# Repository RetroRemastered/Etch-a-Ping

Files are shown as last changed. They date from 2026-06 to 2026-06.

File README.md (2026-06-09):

# Etch-a-PING: Raspberry Pi Pico Pong

`PING` is a MicroPython Pong-inspired game for a Raspberry Pi Pico with real potentiometer paddles, an ILI9225 SPI LCD, a MAX98357A I2S amplifier, and a momentary start button.

It boots to a title screen, plays with an Etch A Sketch-style grey-and-black look, uses classic Pong-like sound effects, and keeps score to 11 with win-by-2 rules.

## Documentation

- [Build tutorial](TUTORIAL.md)
- [Bill of materials](BOM.md)
- [3D print files](3d-print)

## Features

- Raspberry Pi Pico / Pico W firmware in MicroPython
- ILI9225 LCD driver included
- Two analog potentiometer paddles
- MAX98357A I2S audio using RP2040 PIO
- Momentary start button
- 3D printed enclosure files included
- Final score screen
- First to 11, win by 2
- Battery-power notes for TP4056/LiPo builds

## Quick Wiring Summary

| Device | Pico pins |
| --- | --- |
| ILI9225 LCD | `GP17`, `GP18`, `GP19`, `GP20`, `GP21`, `GP22` |
| Potentiometers | `GP26`, `GP27`, `3V3 OUT`, `GND` |
| MAX98357A amp | `GP10`, `GP11`, `GP12` |
| Start button | `GP13`, `GND` |

See [BOM.md](BOM.md) and [TUTORIAL.md](TUTORIAL.md) for the complete wiring tables.

## Install

1. Flash current MicroPython for Raspberry Pi Pico onto the Pico.
2. Open `main.py` in Thonny.
3. Save it to the Pico as `main.py`.
4. Reset the Pico or unplug/replug it.

## 3D Printing

The enclosure files are in [`3d-print`](3d-print):

- [`etch-a-ping-front.stl`](3d-print/etch-a-ping-front.stl)
- [`etch-a-ping-back.stl`](3d-print/etch-a-ping-back.stl)
- [`etch-a-ping-knob.stl`](3d-print/etch-a-ping-knob.stl), print two

## Tuning

- If the screen is only white, the backlight is on but the display is not receiving commands. Recheck `CS`, `RST`, `RS`, `CLK`, and `SDI`.
- To make the game faster or slower, change the `time.sleep_ms(12)` line at the end of the game loop.

## Sources Checked

- Pico pinout: https://pico.pinout.xyz/
- MAX98357A pinout reference: https://learn.adafruit.com/adafruit-max98357-i2s-class-d-mono-amp/pinouts
- ILI9225 register sequence reference: https://os.mbed.com/users/Arman92/code/ILI9225_SPI_TFT/file/cc93245bb6d0/TFT_22_ILI9225.cpp

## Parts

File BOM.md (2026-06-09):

# Bill of Materials

This build is a handheld Raspberry Pi Pico Pong console with real paddle controls, an ILI9225 color LCD, I2S audio, and a start button.

## Required Parts

| Qty | Part | Notes |
| --- | --- | --- |
| 1 | Raspberry Pi Pico | No need for Pico 2. |
| 1 | ILI9225 SPI LCD module | 176 x 220 display, red breakout board. |
| 2 | 10k potentiometers | Linear taper preferred for paddle controls. |
| 1 | MAX98357A I2S mono amplifier | Drives the speaker from Pico digital audio. |
| 1 | Game Boy DMG speaker | 8 ohm speaker for the amp output. |
| 1 | Momentary pushbutton | Start button. |
| 1 | 3.7V LiPo battery | Small Battery that actually fits. |
| 1 | TP4056 LiPo charger/protection board | USB-C version. |
| 1 | Locking on/off switch | Put this between TP4056 `OUT+` and Pico `VSYS`. |
| Several | Jumper wires or hookup wire | 30 AWG is what I use. |

## Case Hardware

| Qty | Part | Notes |
| --- | --- | --- |
| 4 | `M2x4mm` machine screws | Used to mount the screen. |
| 4 | `M2x4x3.2` heat-set inserts | Used in the printed case so the back can screw on cleanly. |
| 4 | `M2x8mm` machine screws | Used with the heat-set inserts to close the two case halves. |

## Part Links

Add direct purchase links here for the exact parts used in your build.

| Part | Link |
| --- | --- |
| Raspberry Pi Pico or Pico W | https://amzn.to/4ftIaCY |
| ILI9225 SPI LCD module | https://amzn.to/4e5MO7L |
| 10k potentiometers | https://amzn.to/4dSDFkc |
| MAX98357A I2S mono amplifier | https://amzn.to/4ogg4NH |
| Game Boy DMG speaker | https://amzn.to/3S9yOTa |
| Momentary pushbutton | https://amzn.to/4um4aTU |
| 3.7V LiPo battery | https://amzn.to/49N2Diw |
| TP4056 LiPo charger/protection board | https://amzn.to/3RUsTRW |
| Locking on/off switch | https://amzn.to/4xhQewU |
| Hookup wire / jumper wire | https://amzn.to/3S8yR1x |
| `M2x4mm` screen screws | https://s.click.aliexpress.com/e/_c4rYxvI9 |
| `M2x4x3.2` heat-set inserts | https://s.click.aliexpress.com/e/_c3U6pgQp |
| `M2x8mm` case screws | https://s.click.aliexpress.com/e/_c4rYxvI9 |

## Tools

| Tool | Use |
| --- | --- |
| Soldering iron | Solder headers and wires. |
| Multimeter | Check continuity and voltages. |
| Computer with Thonny | Flash MicroPython and copy `main.py`. |
| USB cable | Pico programming and testing. |
| Heat-set insert tip or soldering iron | Install threaded inserts into the printed case. |

## Pin Summary

### ILI9225 LCD

| LCD signal | Pico pin |
| --- | --- |
| VCC | `3V3 OUT` |
| GND | `GND` |
| LED | `GP22` |
| CLK | `GP18` |
| SDI | `GP19` |
| RS / DC | `GP20` |
| RST | `GP21` |
| CS | `GP17` |

### Potentiometers

| Control | Pot outer leg | Pot wiper | Pot other outer leg |
| --- | --- | --- | --- |
| Left paddle | `3V3 OUT` | `GP26 / ADC0` | `GND` |
| Right paddle | `3V3 OUT` | `GP27 / ADC1` | `GND` |

If a paddle moves backward, swap that potentiometer's two outer-leg wires.

### MAX98357A Amplifier

| MAX98357A signal | Pico pin |
| --- | --- |
| Vin | `3V3 OUT` or `VSYS` |
| GND | `GND` |
| LRC | `GP10` |
| BCLK | `GP11` |
| DIN | `GP12` |

Connect the speaker to the amplifier screw terminal output. Do not connect a speaker directly to a Pico GPIO pin.

### Start Button

| Button leg | Pico pin |
| --- | --- |
| One side | `GP13` |
| Other side | `GND` |

The firmware uses the Pico internal pull-up resistor.

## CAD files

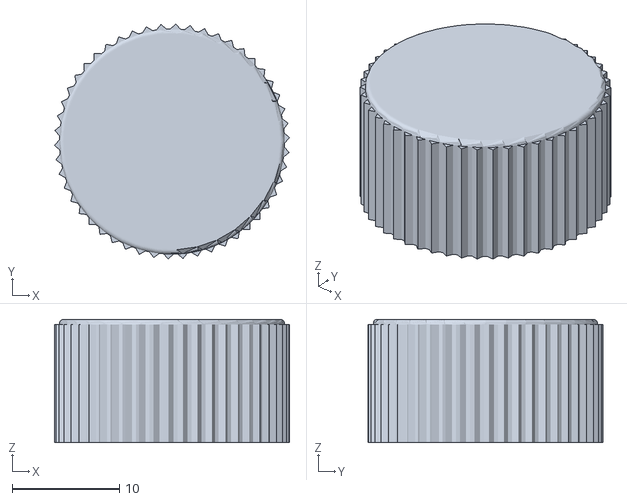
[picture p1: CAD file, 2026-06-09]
3d-print/etch-a-ping-knob.stl
21.9 x 21.9 x 11.5

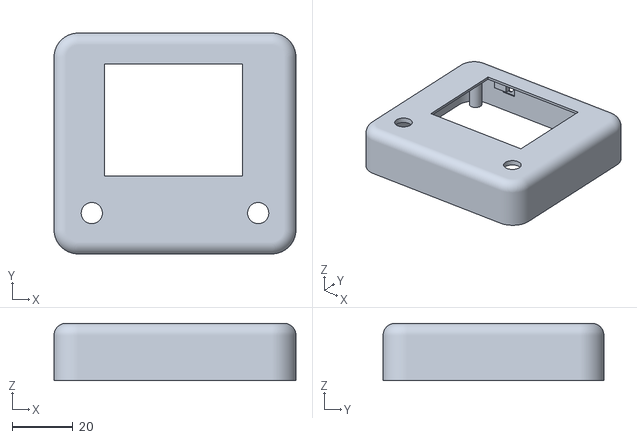
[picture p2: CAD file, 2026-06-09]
3d-print/etch-a-ping-front.stl
80.0 x 73.0 x 19.0

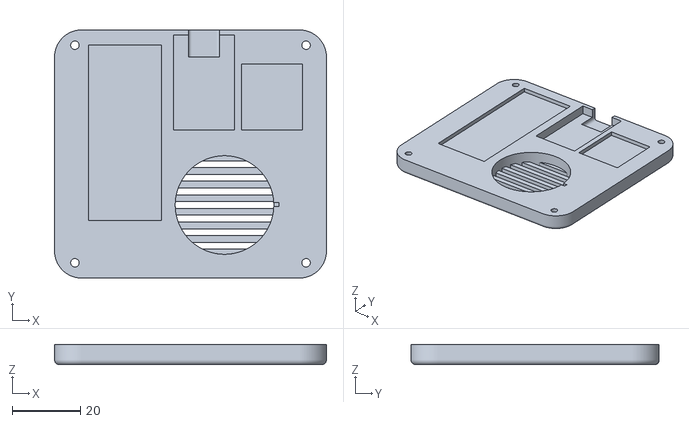
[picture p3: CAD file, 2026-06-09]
3d-print/etch-a-ping-back.stl
80.0 x 73.0 x 6.00

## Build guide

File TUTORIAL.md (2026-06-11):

# Build Tutorial

This written guide follows the same general flow as the video walkthrough: gather the parts, print the enclosure, wire the electronics in small sections, load the firmware, then close it up and play.

You can follow along with me as I build it in this video here: https://youtu.be/AFBS6jwd1_I

`PING` is a Pong-inspired game for Raspberry Pi Pico with real potentiometer paddles, an ILI9225 LCD, MAX98357A audio, a start button, and LiPo battery power.

## 1. Print the Enclosure

The printable parts are in the [`3d-print`](3d-print) folder:

| File | Use |
| --- | --- |
| [`etch-a-ping-front.stl`](3d-print/etch-a-ping-front.stl) | Front shell with the screen and controls. |
| [`etch-a-ping-back.stl`](3d-print/etch-a-ping-back.stl) | Back shell. |
| [`etch-a-ping-knob.stl`](3d-print/etch-a-ping-knob.stl) | Potentiometer knob. Print two knobs. |

Print one front, one back, and two knobs. Test-fit the screen, pots, start button, switch, speaker, Pico, battery, charger board, four `M2x4x3.2` heat-set inserts, four `M2x4mm` screen screws, and four `M2x8mm` case screws before soldering the final wiring. The case is tight, so it is easier to fix fit issues before the wires are attached.

Install the four `M2x4x3.2` heat-set inserts before final assembly. Use a heat-set insert tip or a soldering iron set to a moderate temperature, press each insert in slowly, and let the plastic cool before test-fitting the `M2x8mm` screws. The inserts should sit flush and straight so the back shell closes without stress.

## 2. Flash MicroPython

1. Download the latest MicroPython UF2 for your board:
   - Raspberry Pi Pico: https://micropython.org/download/RPI_PICO/
   - Raspberry Pi Pico W: https://micropython.org/download/RPI_PICO_W/
2. Hold the Pico `BOOTSEL` button while plugging it into USB.
3. Copy the downloaded `.uf2` file to the `RPI-RP2` drive.
4. The Pico will reboot into MicroPython.

After MicroPython is installed, open Thonny and make sure you can connect to the Pico.

## 3. Install the Game

1. Open [`main.py`](main.py) in Thonny.
2. Choose `File` -> `Save As...`.
3. Select `Raspberry Pi Pico`.
4. Save the file as exactly `main.py`.
5. Unplug and reconnect the Pico, or restart the backend in Thonny.

On boot, the screen shows `PING`. Press the start button to begin once the build is wired.

## 4. Prep the Main Parts

Before wiring everything together, mount or test-fit these parts in the printed front shell:

- ILI9225 display
- Two 10k potentiometers
- Momentary start button
- Locking power switch
- Speaker
- Heat-set inserts and case screws

Keep the Pico, MAX98357A amp, TP4056 charger board, and battery loose until the wiring is mostly finished. This makes it easier to route wires without fighting the case.

## 5. Wire the Display

Wire the ILI9225 display first. The display is the trickiest part of the build, so take your time here.

| LCD signal | Pico pin |
| --- | --- |
| VCC | `3V3 OUT` |
| GND | `GND` |
| LED | `GP22` |
| CLK | `GP18` |
| SDI | `GP19` |
| RS / DC | `GP20` |
| RST | `GP21` |
| CS | `GP17` |

If the screen stays white after installing the game, the backlight is powered but the display controller is not receiving commands. Check continuity on `CS`, `CLK`, `SDI`, `RS`, and `RST`.

## 6. Wire the Paddles

Each potentiometer is wired as a voltage divider.

| Control | Pot outer leg | Pot wiper | Pot other outer leg |
| --- | --- | --- | --- |
| Left paddle | `3V3 OUT` | `GP26 / ADC0` | `GND` |
| Right paddle | `3V3 OUT` | `GP27 / ADC1` | `GND` |

Use `3V3 OUT`, not `3V3_EN`. The `3V3_EN` pin controls the Pico regulator and should not be used as the power rail for the potentiometers.

If a paddle moves backward later, swap that potentiometer's two outer-leg wires.

## 7. Wire the Audio

Wire the MAX98357A I2S amplifier.

| MAX98357A signal | Pico pin |
| --- | --- |
| Vin | `3V3 OUT` or `VSYS` |
| GND | `GND` |
| LRC | `GP10` |
| BCLK | `GP11` |
| DIN | `GP12` |

Connect the speaker to the amplifier output terminals. Do not connect the speaker directly to the Pico.

If the amp is silent, connect the amp `SD` pin to `Vin` to force the amp on.

## 8. Wire the Start Button

Wire the normally open momentary switch:

| Button leg | Pico pin |
| --- | --- |
| One side | `GP13` |
| Other side | `GND` |

No external resistor is required because the firmware uses the Pico internal pull-up.

## 9. Wire Battery Power

Use a protected TP4056 charger board with a single-cell 3.7V LiPo.

| Connection | Destination |
| --- | --- |
| LiPo red | TP4056 `B+` |
| LiPo black | TP4056 `B-` |
| TP4056 `OUT+` | Locking switch, then Pico `VSYS` |
| TP4056 `OUT-` | Pico `GND` |

Do not connect battery power to `3V3 OUT`. Use `VSYS`.

The locking switch goes on the positive output side, between TP4056 `OUT+` and Pico `VSYS`. Charge the battery through the TP4056 USB port, not through the Pico USB port.

For small LiPo cells, make sure the TP4056 charge current is appropriate for the battery capacity.

## 10. Final Assembly

Once the screen, controls, audio, and battery wiring all work:

1. Place the screen into the front shell.
2. Secure the screen with four `M2x4mm` screws.
3. Install the potentiometers and knobs.
4. Install the start button and locking power switch.
5. Position the speaker so it is not pressing hard into the screen or Pico.
6. Secure the Pico, amplifier, TP4056 board, and battery.
7. Route wires so the back shell does not pinch them.
8. Close the case with four `M2x8mm` screws threaded into the heat-set inserts.

Power it on with the locking switch, wait for the `PING` title, then press the start button.

## 11. Gameplay

- The first player to reach 11 wins, but they must win by 2 points.
- The score is hidden during active play.
- After each point, the score appears briefly while the paddles can still move.
- After a match ends, the final score remains on screen until the start button is pressed.

## Troubleshooting

### Screen is white

The backlight is powered, but the display controller is not receiving commands. Check `VCC`, `GND`, `CS`, `CLK`, `SDI`, `RS`, and `RST`.

### Audio is silent

Check `Vin`, `GND`, `LRC`, `BCLK`, `DIN`, speaker wiring, and the amp `SD` pin.

### Paddles move backward

Swap the two outer legs of that potentiometer.

### Paddles feel too sensitive

Lower `PADDLE_SENSITIVITY` in `main.py`.

### Ball speed needs tuning

Change `BALL_SPEED` and `SERVE_SPEED` in `main.py`.

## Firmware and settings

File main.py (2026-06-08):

from machine import ADC, Pin, SPI
from rp2 import PIO, StateMachine, asm_pio
import random
import time


# ILI9225 red breakout screen pins, matching your soldered wiring.
LCD_LED = 22
LCD_SCK = 18   # Screen CLK
LCD_MOSI = 19  # Screen SDI
LCD_RS = 20
LCD_RST = 21
LCD_CS = 17

# Two potentiometers. Outer legs go to 3V3 and GND; center wipers go here.
POT_LEFT = 26   # ADC0
POT_RIGHT = 27  # ADC1

# MAX98357A I2S amp pins. These are digital pins so the ADC pins stay free.
I2S_LRC = 10
I2S_BCLK = 11
I2S_DIN = 12
START_BUTTON = 13
AUDIO_RATE = 16_000
AUDIO_VOLUME = 2250
PADDLE_SENSITIVITY = 4

PHYS_WIDTH = 176
PHYS_HEIGHT = 220
WIDTH = 220
HEIGHT = 176
PLAY_LEFT = 0
PLAY_RIGHT = WIDTH

BLACK = 0x0000
WHITE = 0xFFFF
BACKGROUND = 0x8410
FOREGROUND = BLACK
BALL_SPEED = 4
SERVE_SPEED = 3

DIGITS = {
    "0": ("111", "101", "101", "101", "111"),
    "1": ("010", "110", "010", "010", "111"),
    "2": ("111", "001", "111", "100", "111"),
    "3": ("111", "001", "111", "001", "111"),
    "4": ("101", "101", "111", "001", "001"),
    "5": ("111", "100", "111", "001", "111"),
    "6": ("111", "100", "111", "101", "111"),
    "7": ("111", "001", "010", "010", "010"),
    "8": ("111", "101", "111", "101", "111"),
    "9": ("111", "101", "111", "001", "111"),
}

LETTERS = {
    "G": ("01110", "10000", "10000", "10111", "10001", "10001", "01110"),
    "I": ("11111", "00100", "00100", "00100", "00100", "00100", "11111"),
    "N": ("10001", "11001", "10101", "10011", "10001", "10001", "10001"),
    "P": ("11110", "10001", "10001", "11110", "10000", "10000", "10000"),
}


class ILI9225:
    def __init__(self):
        self.spi = SPI(
            0,
            baudrate=16_000_000,
            polarity=0,
            phase=0,
            sck=Pin(LCD_SCK),
            mosi=Pin(LCD_MOSI),
        )
        self.led = Pin(LCD_LED, Pin.OUT, value=1)
        self.rs = Pin(LCD_RS, Pin.OUT, value=0)
        self.cs = Pin(LCD_CS, Pin.OUT, value=1)
        self.rst = Pin(LCD_RST, Pin.OUT, value=1)
        self.init()

    def write_command(self, value):
        self.rs(0)
        self.cs(0)
        self.spi.write(bytes([(value >> 8) & 0xFF, value & 0xFF]))
        self.cs(1)

    def write_data(self, value):
        self.rs(1)
        self.cs(0)
        self.spi.write(bytes([(value >> 8) & 0xFF, value & 0xFF]))
        self.cs(1)

    def write_register(self, reg, value):
        self.write_command(reg)
        self.write_data(value)

    def reset(self):
        self.rst(1)
        time.sleep_ms(5)
        self.rst(0)
        time.sleep_ms(20)
        self.rst(1)
        time.sleep_ms(80)

    def init(self):
        self.reset()

        self.write_register(0x10, 0x0000)
        self.write_register(0x11, 0x0000)
        self.write_register(0x12, 0x0000)
        self.write_register(0x13, 0x0000)
        self.write_register(0x14, 0x0000)
        time.sleep_ms(40)

        self.write_register(0x11, 0x0018)
        self.write_register(0x12, 0x6121)
        self.write_register(0x13, 0x006F)
        self.write_register(0x14, 0x495F)
        self.write_register(0x10, 0x0800)
        time.sleep_ms(10)
        self.write_register(0x11, 0x103B)
        time.sleep_ms(50)

        self.write_register(0x01, 0x011C)
        self.write_register(0x02, 0x0100)
        self.write_register(0x03, 0x1030)
        self.write_register(0x07, 0x0000)
        self.write_register(0x08, 0x0808)
        self.write_register(0x0B, 0x1100)
        self.write_register(0x0C, 0x0000)
        self.write_register(0x0F, 0x0D01)
        self.write_register(0x15, 0x0020)
        self.write_register(0x20, 0x0000)
        self.write_register(0x21, 0x0000)

        self.write_register(0x30, 0x0000)
        self.write_register(0x31, 0x00DB)
        self.write_register(0x32, 0x0000)
        self.write_register(0x33, 0x0000)
        self.write_register(0x34, 0x00DB)
        self.write_register(0x35, 0x0000)
        self.write_register(0x36, 0x00AF)
        self.write_register(0x37, 0x0000)
        self.write_register(0x38, 0x00DB)
        self.write_register(0x39, 0x0000)

        self.write_register(0x50, 0x0000)
        self.write_register(0x51, 0x0808)
        self.write_register(0x52, 0x080A)
        self.write_register(0x53, 0x000A)
        self.write_register(0x54, 0x0A08)
        self.write_register(0x55, 0x0808)
        self.write_register(0x56, 0x0000)
        self.write_register(0x57, 0x0A00)
        self.write_register(0x58, 0x0710)
        self.write_register(0x59, 0x0710)

        self.write_register(0x07, 0x0012)
        time.sleep_ms(50)
        self.write_register(0x07, 0x1017)
        time.sleep_ms(100)
        self.fill(BACKGROUND)

    def orient(self, x, y):
        return y, PHYS_HEIGHT - x - 1

    def set_window(self, x0, y0, x1, y1):
        x0, y0 = self.orient(x0, y0)
        x1, y1 = self.orient(x1, y1)
        if x1 < x0:
            x0, x1 = x1, x0
        if y1 < y0:
            y0, y1 = y1, y0

        self.write_register(0x36, x1)
        self.write_register(0x37, x0)
        self.write_register(0x38, y1)
        self.write_register(0x39, y0)
        self.write_register(0x20, x0)
        self.write_register(0x21, y0)
        self.write_command(0x0022)

    def fill_rect(self, x, y, w, h, color):
        if w <= 0 or h <= 0:
            return
        x0 = max(0, x)
        y0 = max(0, y)
        x1 = min(WIDTH - 1, x + w - 1)
        y1 = min(HEIGHT - 1, y + h - 1)
        if x0 > x1 or y0 > y1:
            return

        hi = color >> 8
        lo = color & 0xFF
        pixel = bytes([hi, lo])
        count = (x1 - x0 + 1) * (y1 - y0 + 1)
        chunk = pixel * min(count, 256)

        self.set_window(x0, y0, x1, y1)
        self.cs(0)
        self.rs(1)
        while count:
            n = min(count, 256)
            self.spi.write(chunk[: n * 2])
            count -= n
        self.cs(1)

    def fill(self, color):
        self.fill_rect(0, 0, WIDTH, HEIGHT, color)

    def blit_rgb565(self, x, y, w, h, buffer):
        if w <= 0 or h <= 0:
            return
        self.set_window(x, y, x + w - 1, y + h - 1)
        self.cs(0)
        self.rs(1)
        self.spi.write(buffer)
        self.cs(1)


def clamp(value, lo, hi):
    return max(lo, min(hi, value))


def pot_to_y(adc, paddle_h):
    raw = adc.read_u16()
    raw = clamp((raw - 32768) * PADDLE_SENSITIVITY + 32768, 0, 65535)
    return -paddle_h // 2 + (raw * HEIGHT) // 65535


def auto_y(ball_y, paddle_h):
    return clamp(ball_y - paddle_h // 2, -paddle_h // 2, HEIGHT - paddle_h // 2)


def reset_ball(direction=None):
    dx = direction if direction else random.choice((-SERVE_SPEED, SERVE_SPEED))
    dy = random.choice((-3, -2, 2, 3))
    return (PLAY_LEFT + PLAY_RIGHT) // 2, HEIGHT // 2, dx, dy


def has_winner(score_l, score_r):
    if score_l >= 11 and score_l - score_r >= 2:
        return 1
    if score_r >= 11 and score_r - score_l >= 2:
        return 2
    return 0


def draw_digit_to_buffer(buffer, area_w, digit, x, y, scale, color):
    rows = DIGITS[str(digit)]
    hi = color >> 8
    lo = color & 0xFF
    for row_i, row in enumerate(rows):
        for col_i, pixel in enumerate(row):
            if pixel != "1":
                continue
            px = x + col_i * scale
            py = y + row_i * scale
            for yy in range(py, py + scale):
                for xx in range(px, px + scale):
                    offset = (yy * area_w + xx) * 2
                    buffer[offset] = hi
                    buffer[offset + 1] = lo


def draw_number_to_buffer(buffer, area_w, value, x, y, scale, color):
    text = str(value)
    digit_w = 3 * scale
    gap = scale
    for i, digit in enumerate(text):
        draw_digit_to_buffer(buffer, area_w, digit, x + i * (digit_w + gap), y, scale, color)


def draw_digit(lcd, digit, x, y, scale, color):
    rows = DIGITS[str(digit)]
    for row_i, row in enumerate(rows):
        for col_i, pixel in enumerate(row):
            if pixel == "1":
                lcd.fill_rect(
                    x + col_i * scale,
                    y + row_i * scale,
                    scale,
                    scale,
                    color,
                )


def draw_number(lcd, value, x, y, scale, color):
    text = str(value)
    digit_w = 3 * scale
    gap = scale
    for i, digit in enumerate(text):
        draw_digit(lcd, digit, x + i * (digit_w + gap), y, scale, color)


def number_width(value, scale):
    return len(str(value)) * 3 * scale + max(0, len(str(value)) - 1) * scale


def draw_letter(lcd, letter, x, y, scale, color):
    rows = LETTERS[letter]
    for row_i, row in enumerate(rows):
        for col_i, pixel in enumerate(row):
            if pixel == "1":
                lcd.fill_rect(
                    x + col_i * scale,
                    y + row_i * scale,
                    scale,
                    scale,
                    color,
                )


def draw_text(lcd, text, x, y, scale, color):
    letter_w = 5 * scale
    gap = scale
    for i, letter in enumerate(text):
        draw_letter(lcd, letter, x + i * (letter_w + gap), y, scale, color)


def text_width(text, scale):
    return len(text) * 5 * scale + max(0, len(text) - 1) * scale


def wait_for_start(lcd, button):
    lcd.fill(BACKGROUND)
    scale = 8
    title = "PING"
    x = (WIDTH - text_width(title, scale)) // 2
    y = (HEIGHT - 7 * scale) // 2
    draw_text(lcd, title, x, y, scale, FOREGROUND)

    while button.value() == 0:
        time.sleep_ms(20)
    while button.value() == 1:
        time.sleep_ms(20)
    time.sleep_ms(80)
    while button.value() == 0:
        time.sleep_ms(20)

    lcd.fill(BACKGROUND)
    time.sleep_ms(650)


def wait_for_button_press(button):
    while button.value() == 0:
        time.sleep_ms(20)
    while button.value() == 1:
        time.sleep_ms(20)
    time.sleep_ms(80)
    while button.value() == 0:
        time.sleep_ms(20)


def draw_scoreboard(lcd, score_l, score_r):
    lcd.fill_rect(64, 5, 92, 18, BACKGROUND)
    scale = 3
    left_w = number_width(score_l, scale)
    draw_number(lcd, score_l, WIDTH // 2 - 18 - left_w, 6, scale, FOREGROUND)
    draw_number(lcd, score_r, WIDTH // 2 + 18, 6, scale, FOREGROUND)


def clear_scoreboard(lcd):
    lcd.fill_rect(64, 5, 92, 18, BACKGROUND)


def wait_with_score(
    lcd,
    left_pot,
    right_pot,
    left_x,
    right_x,
    paddle_w,
    paddle_h,
    score_l,
    score_r,
    last_left_y,
    last_right_y,
):
    end_at = time.ticks_add(time.ticks_ms(), 900)
    while time.ticks_diff(end_at, time.ticks_ms()) > 0:
        left_y = pot_to_y(left_pot, paddle_h) if left_pot else HEIGHT // 2 - paddle_h // 2
        right_y = pot_to_y(right_pot, paddle_h) if right_pot else HEIGHT // 2 - paddle_h // 2
        draw_paddle_during_pause(lcd, left_x, last_left_y, left_y, paddle_w, paddle_h)
        draw_paddle_during_pause(lcd, right_x, last_right_y, right_y, paddle_w, paddle_h)
        last_left_y = left_y
        last_right_y = right_y
        time.sleep_ms(12)
    return last_left_y, last_right_y


def show_winner(lcd, score_l, score_r, winner):
    lcd.fill(BACKGROUND)
    scale = 7
    left_w = number_width(score_l, scale)
    right_w = number_width(score_r, scale)
    left_x = (WIDTH // 4) - (left_w // 2)
    right_x = (WIDTH * 3 // 4) - (right_w // 2)
    y = HEIGHT // 2 - 18
    draw_number(lcd, score_l, left_x, y, scale, FOREGROUND)
    draw_number(lcd, score_r, right_x, y, scale, FOREGROUND)
    if winner == 1:
        lcd.fill_rect(left_x, y + 42, left_w, 4, FOREGROUND)
    else:
        lcd.fill_rect(right_x, y + 42, right_w, 4, FOREGROUND)


def paddle_deflection(ball_y, ball_size, paddle_y, paddle_h):
    ball_center = ball_y + ball_size // 2
    paddle_center = paddle_y + paddle_h // 2
    offset = ball_center - paddle_center
    max_offset = max(1, paddle_h // 2)
    return clamp((offset * 4) // max_offset, -4, 4)


def rects_overlap(ax, ay, aw, ah, bx, by, bw, bh):
    return ax < bx + bw and ax + aw > bx and ay < by + bh and ay + ah > by


def ball_touched_paddle_area(ball_x, ball_y, ball_size, paddle_x, old_y, new_y, paddle_w, paddle_h):
    if old_y != -1 and rects_overlap(
        ball_x, ball_y, ball_size, ball_size, paddle_x, old_y, paddle_w, paddle_h
    ):
        return True
    return rects_overlap(
        ball_x, ball_y, ball_size, ball_size, paddle_x, new_y, paddle_w, paddle_h
    )


def draw_paddle(lcd, x, old_y, new_y, w, h, force=False):
    if old_y == -1 or force:
        if old_y != -1:
            lcd.fill_rect(x, old_y, w, h, BACKGROUND)
        lcd.fill_rect(x, new_y, w, h, FOREGROUND)
        return

    if new_y == old_y:
        return

    old_top = max(0, old_y)
    old_bottom = min(HEIGHT, old_y + h)
    new_top = max(0, new_y)
    new_bottom = min(HEIGHT, new_y + h)

    if old_top < old_bottom:
        if old_top < new_top:
            lcd.fill_rect(x, old_top, w, min(old_bottom, new_top) - old_top, BACKGROUND)
        if old_bottom > new_bottom:
            lcd.fill_rect(x, max(old_top, new_bottom), w, old_bottom - max(old_top, new_bottom), BACKGROUND)

    if new_top < new_bottom:
        if new_top < old_top:
            lcd.fill_rect(x, new_top, w, min(new_bottom, old_top) - new_top, FOREGROUND)
        if new_bottom > old_bottom:
            lcd.fill_rect(x, max(new_top, old_bottom), w, new_bottom - max(new_top, old_bottom), FOREGROUND)


def draw_paddle_during_pause(lcd, x, old_y, new_y, w, h):
    if old_y < 0 or old_y + h > HEIGHT or new_y < 0 or new_y + h > HEIGHT:
        lcd.fill_rect(x, 0, w, HEIGHT, BACKGROUND)
        lcd.fill_rect(x, new_y, w, h, FOREGROUND)
    else:
        draw_paddle(lcd, x, old_y, new_y, w, h)


@asm_pio(
    out_init=PIO.OUT_LOW,
    set_init=PIO.OUT_LOW,
    out_shiftdir=PIO.SHIFT_LEFT,
    autopull=True,
    pull_thresh=32,
    sideset_init=PIO.OUT_LOW,
)
def i2s_square_wave_out():
    set(pins, 0).side(0)
    set(x, 15)
    label("left")
    out(pins, 1).side(0)
    nop().side(1)
    jmp(x_dec, "left").side(0)
    set(pins, 1).side(0)
    set(x, 15)
    label("right")
    out(pins, 1).side(0)
    nop().side(1)
    jmp(x_dec, "right").side(0)


class Beeper:
    def __init__(self):
        self.audio = StateMachine(
            0,
            i2s_square_wave_out,
            freq=AUDIO_RATE * 32 * 3,
            out_base=Pin(I2S_DIN),
            set_base=Pin(I2S_LRC),
            sideset_base=Pin(I2S_BCLK),
        )
        self.audio.active(1)

    def beep(self, freq, duration_ms=35):
        sample_count = max(1, (AUDIO_RATE * duration_ms) // 1000)
        period = max(2, AUDIO_RATE // freq)
        half_period = period // 2

        for i in range(sample_count):
            sample = AUDIO_VOLUME if i % period < half_period else -AUDIO_VOLUME
            if sample < 0:
                sample += 65536
            self.audio.put((sample << 16) | sample)

    def update(self):
        pass

    def score(self):
        self.beep(60, 20)


def update_paddles_once(lcd, left_pot, right_pot, left_x, right_x, paddle_w, paddle_h, last_left_y, last_right_y):
    left_y = pot_to_y(left_pot, paddle_h) if left_pot else HEIGHT // 2 - paddle_h // 2
    right_y = pot_to_y(right_pot, paddle_h) if right_pot else HEIGHT // 2 - paddle_h // 2
    draw_paddle_during_pause(lcd, left_x, last_left_y, left_y, paddle_w, paddle_h)
    draw_paddle_during_pause(lcd, right_x, last_right_y, right_y, paddle_w, paddle_h)
    return left_y, right_y


def main():
    lcd = ILI9225()
    left_pot = ADC(POT_LEFT) if POT_LEFT is not None else None
    right_pot = ADC(POT_RIGHT) if POT_RIGHT is not None else None
    start_button = Pin(START_BUTTON, Pin.IN, Pin.PULL_UP)
    beeper = Beeper()
    wait_for_start(lcd, start_button)

    paddle_w = 5
    paddle_h = 34
    ball_size = 5
    left_x = PLAY_LEFT + 8
    right_x = PLAY_RIGHT - 13
    score_l = 0
    score_r = 0
    ball_x, ball_y, ball_dx, ball_dy = reset_ball()

    last_left_y = last_right_y = -1
    last_ball_x = last_ball_y = -1

    lcd.fill(BACKGROUND)

    while True:
        beeper.update()

        left_y = pot_to_y(left_pot, paddle_h) if left_pot else auto_y(ball_y, paddle_h)
        right_y = pot_to_y(right_pot, paddle_h) if right_pot else auto_y(ball_y, paddle_h)

        next_x = ball_x + ball_dx
        next_y = ball_y + ball_dy

        if next_y <= 0 or next_y >= HEIGHT - ball_size:
            ball_dy = -ball_dy
            next_y = ball_y + ball_dy
            beeper.beep(500, 35)

        left_hit = (
            next_x <= left_x + paddle_w
            and next_x + ball_size >= left_x
            and next_y + ball_size >= left_y
            and next_y <= left_y + paddle_h
        )
        right_hit = (
            next_x + ball_size >= right_x
            and next_x <= right_x + paddle_w
            and next_y + ball_size >= right_y
            and next_y <= right_y + paddle_h
        )

        if left_hit:
            ball_dx = BALL_SPEED
            ball_dy = paddle_deflection(next_y, ball_size, left_y, paddle_h)
            next_x = left_x + paddle_w + 1
            beeper.beep(1000, 35)
        elif right_hit:
            ball_dx = -BALL_SPEED
            ball_dy = paddle_deflection(next_y, ball_size, right_y, paddle_h)
            next_x = right_x - ball_size - 1
            beeper.beep(1000, 35)

        if next_x < PLAY_LEFT:
            score_r += 1
            beeper.score()
            winner = has_winner(score_l, score_r)
            if winner:
                show_winner(lcd, score_l, score_r, winner)
                wait_for_button_press(start_button)
                score_l = 0
                score_r = 0
                lcd.fill(BACKGROUND)
                time.sleep_ms(650)
                last_left_y = last_right_y = -1
                last_ball_x = last_ball_y = -1
                ball_x, ball_y, ball_dx, ball_dy = reset_ball(-SERVE_SPEED)
                continue
            lcd.fill_rect(ball_x, ball_y, ball_size, ball_size, BACKGROUND)
            last_left_y, last_right_y = update_paddles_once(
                lcd, left_pot, right_pot, left_x, right_x, paddle_w, paddle_h, last_left_y, last_right_y
            )
            draw_scoreboard(lcd, score_l, score_r)
            last_left_y, last_right_y = wait_with_score(
                lcd,
                left_pot,
                right_pot,
                left_x,
                right_x,
                paddle_w,
                paddle_h,
                score_l,
                score_r,
                last_left_y,
                last_right_y,
            )
            clear_scoreboard(lcd)
            last_left_y, last_right_y = update_paddles_once(
                lcd, left_pot, right_pot, left_x, right_x, paddle_w, paddle_h, last_left_y, last_right_y
            )
            ball_x, ball_y, ball_dx, ball_dy = reset_ball(-SERVE_SPEED)
            last_ball_x = last_ball_y = -1
            beeper.update()
            continue
        if next_x > PLAY_RIGHT - ball_size:
            score_l += 1
            beeper.score()
            winner = has_winner(score_l, score_r)
            if winner:
                show_winner(lcd, score_l, score_r, winner)
                wait_for_button_press(start_button)
                score_l = 0
                score_r = 0
                lcd.fill(BACKGROUND)
                time.sleep_ms(650)
                last_left_y = last_right_y = -1
                last_ball_x = last_ball_y = -1
                ball_x, ball_y, ball_dx, ball_dy = reset_ball(SERVE_SPEED)
                continue
            lcd.fill_rect(ball_x, ball_y, ball_size, ball_size, BACKGROUND)
            last_left_y, last_right_y = update_paddles_once(
                lcd, left_pot, right_pot, left_x, right_x, paddle_w, paddle_h, last_left_y, last_right_y
            )
            draw_scoreboard(lcd, score_l, score_r)
            last_left_y, last_right_y = wait_with_score(
                lcd,
                left_pot,
                right_pot,
                left_x,
                right_x,
                paddle_w,
                paddle_h,
                score_l,
                score_r,
                last_left_y,
                last_right_y,
            )
            clear_scoreboard(lcd)
            last_left_y, last_right_y = update_paddles_once(
                lcd, left_pot, right_pot, left_x, right_x, paddle_w, paddle_h, last_left_y, last_right_y
            )
            ball_x, ball_y, ball_dx, ball_dy = reset_ball(SERVE_SPEED)
            last_ball_x = last_ball_y = -1
            beeper.update()
            continue

        if last_ball_x != -1:
            lcd.fill_rect(last_ball_x, last_ball_y, ball_size, ball_size, BACKGROUND)

        ball_x, ball_y = next_x, next_y

        redraw_left = last_ball_x != -1 and ball_touched_paddle_area(
            last_ball_x, last_ball_y, ball_size, left_x, last_left_y, left_y, paddle_w, paddle_h
        )
        redraw_right = last_ball_x != -1 and ball_touched_paddle_area(
            last_ball_x, last_ball_y, ball_size, right_x, last_right_y, right_y, paddle_w, paddle_h
        )

        draw_paddle(lcd, left_x, last_left_y, left_y, paddle_w, paddle_h, redraw_left)
        draw_paddle(lcd, right_x, last_right_y, right_y, paddle_w, paddle_h, redraw_right)
        lcd.fill_rect(ball_x, ball_y, ball_size, ball_size, FOREGROUND)

        last_left_y = left_y
        last_right_y = right_y
        last_ball_x = ball_x
        last_ball_y = ball_y

        time.sleep_ms(12)


main()

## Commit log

2026-06-08 Initial Pico Pong project
2026-06-08 Update BOM with battery parts and links
2026-06-09 Add print files and update build tutorial
    [etch-a-ping-back.stl, etch-a-ping-front.stl, etch-a-ping-knob.stl]
2026-06-09 Add case hardware to BOM and tutorial
2026-06-09 Document case screw sizes
2026-06-09 Add heat-set insert link
2026-06-09 Add screw set link
